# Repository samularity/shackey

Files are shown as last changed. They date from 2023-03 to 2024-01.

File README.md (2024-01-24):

# shackey 

### a simple ESP32-C3 SSH Client  

It's main (and only goal) is to open or close the [shackspace portal](https://github.com/shackspace/portal300) with a button press on a keychain device. 

### $\color{#D29922}\textsf{\Large\&#x26A0;\kern{0.2cm}\normalsize  !! Hardware-Issues !! \Large\&#x26A0; }$ 

- LED2 Green is on in DeepSleep FIX: Remove R7
- U4 XB6042J2SV-L is not working as expected
    - FIX: Bridge B_GND and GND
    - !Warning! This disables undervoltage protection

### How it works

- deepsleep
- Read two buttons (and Reset Pin) to open or close
- connect to wifi
- open a SSH session with your private key on a remote server
- provide a webserver to upload or delete your key

```mermaid
graph TD
    NodeStart((deepsleep)) --> wakeup -- wakup-source --> NodeWAKE{ } 

    wakeup -- enable --> NodeTimer{{45sec watchdog timer}} -. Timeout .-> NodeZZZ

    NodeWAKE -->|"BtnRst || Btn1+2"| NodeK(["setup-mode"]) -->  NodeClient
    NodeClient --> NodeClient
    NodeClient["wait for client"] --> connected -- disable --> NodeTimer

    NodeWAKE -->|Btn1| NodeJ([open]) -- set cmd=open--> NodeWIFI
    NodeWAKE -->|Btn2| NodeI([close]) -- set cmd=close--> NodeWIFI

    NodeWIFI["connect to wifi"] -- connected --> NodeCMD["ssh cmd"] -- got response --> NodeZZZ
    NodeWIFI-->NodeWIFI
    NodeCMD --> NodeCMD

    NodeWAKE -->|BtnRst| NodeZZZ  

    NodeZZZ((deepsleep))
```

### Software components used
- libssh2 ~~latest version~~ [463449fb](https://github.com/libssh2/libssh2/tree/463449fb9ee7dbe5fbe71a28494579a9a6890d6d) is used without any modifications.  
- It's arduino free without any outdated dependencies or additional overhead.  
- Its based on the latest espidf supported by platformio.

### ESP32-Connection

| PIN-Number | ESP-Pin Name | Description  |
|----|---|---|
|  6 | GPIO2 | 10k Pullup |
| 14 | GPIO8 | 10k Pullup |
| 15 | GPIO9 | BOOT |
|  4 | GPIO0 / XTAL_32K_P | Enable ADC |
| 27 | GPIO20 / U0RXD | ADC |
|  9 | GPIO4 / MTMS | SW1 Close (High when pressed) |
| 10 | GPIO5 / MTDI | SW2 Open (High pressed) |
| 16 | GPIO10 | LED1 Green |
| 12 | GPIO6 / MTCK | LED1 Red |
| 13 | GPIO7 / MTDO | LED1 Blue |
| 18 | GPIO11 / VDD_SPI | LED2 Green |
|  8 | GPIO3 | LED2 Red |
|  5 | GPIO1 / XTAL_32K_N | LED2 Blue |
| 28 | GPIO21 / U0TXD | TX-Testpin |
|  7 | Chip_EN | Reset |

### Device-Setup

- short the boot pin and upload firmware
- enter setup-mode by pressing both buttons on startup
- upload you private and public key with the following name
  "key.pub" und "key"

### thx & refs

- https://github.com/libssh2/libssh2
- https://github.com/espressif/esp-idf/tree/master/examples/
- https://www.ewan.cc/?q=node/157
- https://github.com/ewpa/LibSSH-ESP32
- https://github.com/nopnop2002/esp-idf-ssh-client
- https://wcalc.sourceforge.net/cgi-bin/coplanar.cgi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

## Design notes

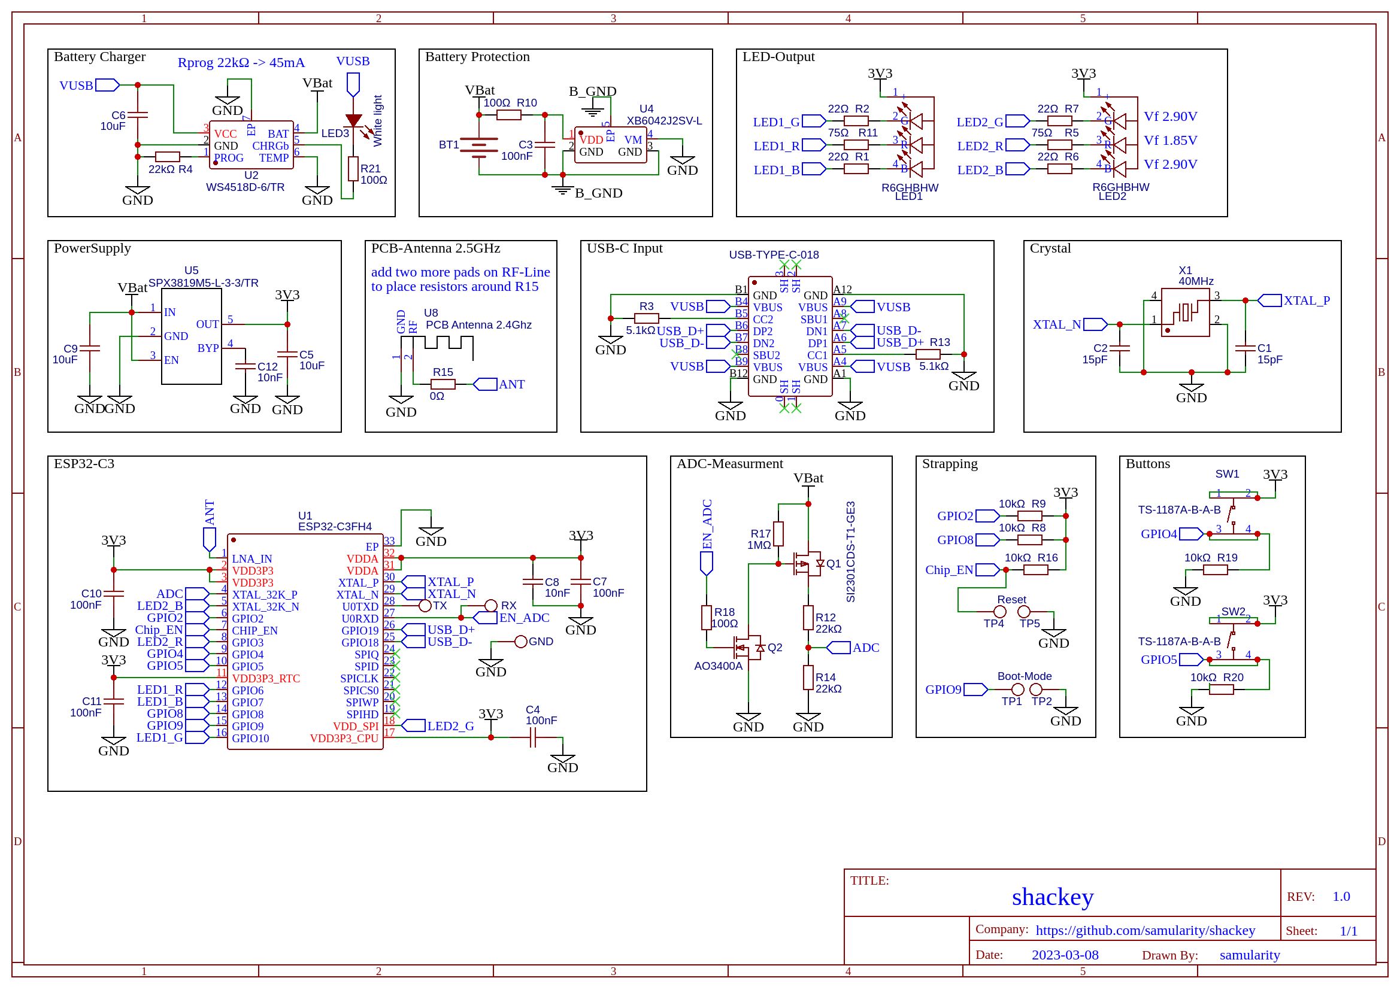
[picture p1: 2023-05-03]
hardware/schematic_shackey_final_1mmslot_2023-04-06.png

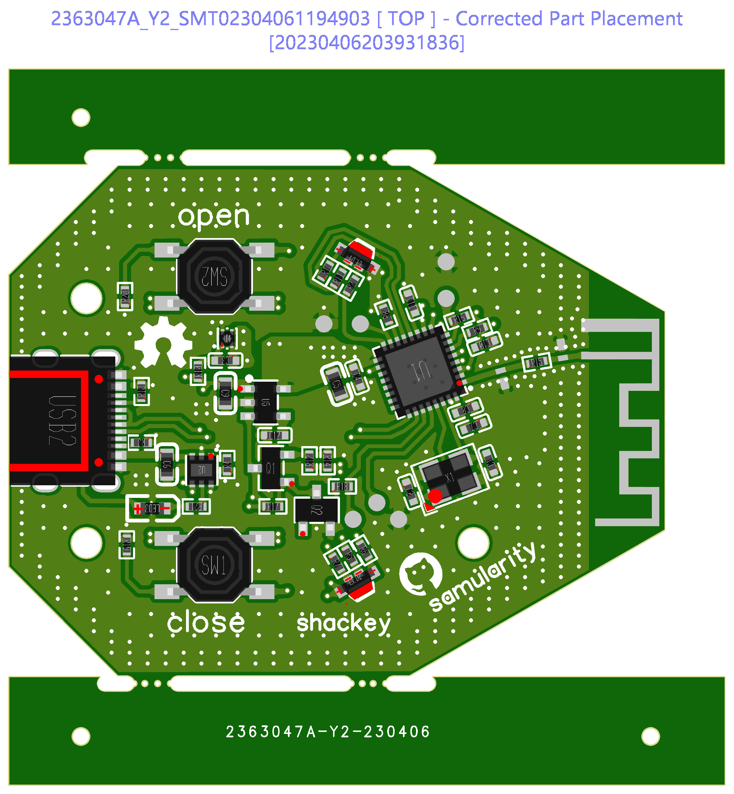
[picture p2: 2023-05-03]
hardware/pcb_shackey_final_1mmslot_2023-04-06.png

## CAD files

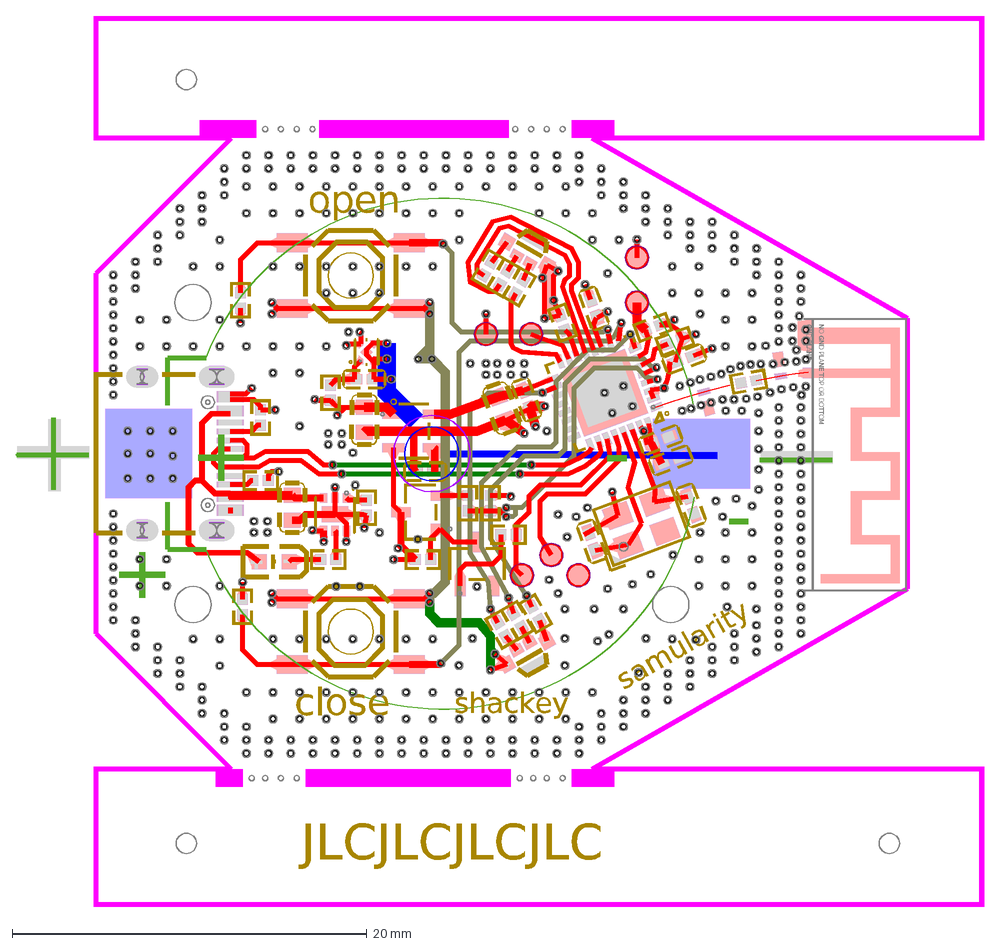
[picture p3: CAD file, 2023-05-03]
hardware/outline_shackey_final_1mmslot_2023-04-06.dxf
+
-
open
close
samularity
shackey
JLCJLCJLCJLC
GND PLANE
NO GND PLANE TOP OR BOTTOM

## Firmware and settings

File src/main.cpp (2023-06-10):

// Stack size needed to run SSH and the command parser.
const unsigned int configSTACK = 51200;

#include <errno.h>
#include <stdio.h>
#include <stdlib.h>
#include <string.h>
#include "driver/uart.h"
#include "esp_vfs_dev.h"
#include "driver/gpio.h"
#include "driver/ledc.h"
#include "nvs_flash.h"
#include "nvs.h"
#include "esp_timer.h"
#include "esp_log.h"
//own header
#include "pwrmgr.h"
#include "ssh.h"
#include "sspiffs.h"
#include "wifi.h"
#include "webserver.h"
#include "dns_server.h"

/*
| PIN-Number | ESP-Pin Name | Description  |
|----|----------------------|--------------|
|  4 | GPIO0 / XTAL_32K_P   | Enable ADC   |
| 27 | GPIO20 / U0RXD       | ADC          |
|  9 | GPIO4 / MTMS         | SW1 Close (High when pressed) |
| 10 | GPIO5 / MTDI         | SW2 Open (High pressed) |
| 16 | GPIO10               | LED1 Green   |
| 12 | GPIO6 / MTCK         | LED1 Red     |
| 13 | GPIO7 / MTDO         | LED1 Blue    |
| 18 | GPIO11 / VDD_SPI     | LED2 Green   |
|  8 | GPIO3                | LED2 Red     |
|  5 | GPIO1 / XTAL_32K_N   | LED2 Blue    |
*/
#define GPIO_ADC_ENABLE GPIO_NUM_0
#define GPIO_ADC_READ GPIO_NUM_20

#define GPIO_SW_CLOSE GPIO_NUM_4
#define GPIO_SW_OPEN GPIO_NUM_5

#define GPIO_LED1_RED GPIO_NUM_6
#define GPIO_LED1_GREEN GPIO_NUM_10
#define GPIO_LED1_BLUE GPIO_NUM_7

#define GPIO_LED2_RED GPIO_NUM_3
#define GPIO_LED2_GREEN GPIO_NUM_11 //DOES NOT WORK as GPIO, RESERVED for VDD_SPI
#define GPIO_LED2_BLUE GPIO_NUM_1

#define LEDC_TIMER              LEDC_TIMER_0
#define LEDC_MODE               LEDC_LOW_SPEED_MODE
#define LEDC_CHANNEL            LEDC_CHANNEL_0
#define LEDC_DUTY_RES           LEDC_TIMER_13_BIT // Set duty resolution to 13 bits
#define LEDC_DUTY               (1000) // Set duty to 50%. ((2 ** 13) - 1) * 50% = 4095  max 8191
#define LEDC_FREQUENCY          (5000) // Frequency in Hertz. Set frequency at 5 kHz



EventGroupHandle_t s_wifi_event_group;
EventGroupHandle_t xEventGroup;

int TASK_FINISH_BIT	= BIT4;

void TimeoutLoop(void *pvParameter){

  vTaskDelay(1000 / portTICK_PERIOD_MS);//wait 1 second to make sure buttons are released after setup-mode

 
  while (1){
    vTaskDelay(100 / portTICK_PERIOD_MS);

    if (1 == gpio_get_level(GPIO_SW_OPEN) &&  1 == gpio_get_level(GPIO_SW_CLOSE) ) {
      //abort whatever is going on
      printf("abort!\n");
      vTaskDelay(1000 / portTICK_PERIOD_MS);
      enterDeepsleep();
    }

    if ((esp_timer_get_time() > 45*1000*1000)){//uptime > 45 sec 
      //check if we are in setup mode and a client is connected
      if ( (xEventGroupGetBits(s_wifi_event_group) & WIFI_CLIENT_CONNECTED_BIT) ){
        printf("stay awake forever\n");
      }
      else{
        printf("took too long\n");
        enterDeepsleep();
      }
    } 
  }
  vTaskDelete( NULL ); //exit
}


void SetupMode (void *pvParameter){

  //esp_log_level_set("wifi", ESP_LOG_DEBUG);
  wifi_init_softap();
  start_webserver();
  start_dns_server();

  //idle forever, exit is handled in TimeoutLoop
  while (1){ vTaskDelay(1000 / portTICK_PERIOD_MS); }
}


extern "C" void app_main() {
  
  sshParameter cfg = {
    .username = "close",
    .hostname = "portal.shackspace.de",
    .port = 22,
    .password = {'\0'},
    .publickey = "/spiffs/key.pub",
    .privatekey = "/spiffs/key",
    .cmd = {'\0'},
  };

  // Use the expected blocking I/O behavior.
  setvbuf(stdin, NULL, _IONBF, 0);
  setvbuf(stdout, NULL, _IONBF, 0);

  //GPIO-INIT

  //configure inputs
	gpio_config_t io_conf;
	io_conf.intr_type = GPIO_INTR_DISABLE;
	io_conf.mode = GPIO_MODE_INPUT;
  io_conf.pin_bit_mask = ( (1ULL<<GPIO_SW_CLOSE) | (1ULL<<GPIO_SW_OPEN) );
	io_conf.pull_down_en = GPIO_PULLDOWN_ENABLE;
	io_conf.pull_up_en = GPIO_PULLUP_DISABLE;
	gpio_config(&io_conf);

	io_conf.pin_bit_mask = (1ULL<<GPIO_ADC_READ);
  io_conf.pull_up_en = GPIO_PULLUP_DISABLE;
	io_conf.pull_down_en = GPIO_PULLDOWN_DISABLE;
	gpio_config(&io_conf);

  //configure outputs
	io_conf.mode = GPIO_MODE_OUTPUT;
	io_conf.pin_bit_mask = ( (1ULL<<GPIO_ADC_ENABLE) |  (1ULL<<GPIO_LED1_RED) | (1ULL<<GPIO_LED1_GREEN) | (1ULL<<GPIO_LED1_BLUE) | (1ULL<<GPIO_LED2_RED) | (1ULL<<GPIO_LED2_BLUE)  );
  io_conf.pull_up_en = GPIO_PULLUP_DISABLE;
  io_conf.pull_down_en = GPIO_PULLDOWN_DISABLE;
  gpio_config(&io_conf);

//Disable all LEDs

  gpio_set_level(GPIO_LED2_BLUE, 0); //start led
  gpio_set_level(GPIO_LED1_RED, 1);
  gpio_set_level(GPIO_LED1_GREEN, 1);
  gpio_set_level(GPIO_LED1_BLUE, 1);
  gpio_set_level(GPIO_LED2_RED, 1);
	gpio_set_level(GPIO_LED2_GREEN, 1);


  uart_driver_install ((uart_port_t)CONFIG_ESP_CONSOLE_UART_NUM, 256, 0, 0, NULL, 0);
  esp_vfs_dev_uart_use_driver(CONFIG_ESP_CONSOLE_UART_NUM);

 // Prepare and then apply the LEDC PWM timer configuration
    ledc_timer_config_t ledc_timer = {
        .speed_mode       = LEDC_MODE,
        .duty_resolution  = LEDC_DUTY_RES,
        .timer_num        = LEDC_TIMER,
        .freq_hz          = LEDC_FREQUENCY,  // Set output frequency at 5 kHz
        .clk_cfg          = LEDC_AUTO_CLK
    };
    ESP_ERROR_CHECK(ledc_timer_config(&ledc_timer));

    // Prepare and then apply the LEDC PWM channel configuration
    ledc_channel_config_t ledc_channel = {
        .gpio_num       = GPIO_LED1_GREEN,
        .speed_mode     = LEDC_MODE,
        .channel        = LEDC_CHANNEL,
        .intr_type      = LEDC_INTR_DISABLE,
        .timer_sel      = LEDC_TIMER,
        .duty           = 0, // Set duty to 0%  //[0, (2**duty_resolution) - 1] 
        .hpoint         = 0,
        .flags          = 1
    };

  ledc_channel_config(&ledc_channel);

  printf("starting...\n");

  esp_log_level_set("SSH", ESP_LOG_DEBUG);

  printf("%s:%d: %llums\n",__FILE__ , __LINE__ , (uint64_t) (esp_timer_get_time()/1000) );

  s_wifi_event_group = xEventGroupCreate();
  xEventGroupClearBits( s_wifi_event_group, WIFI_CONNECTED_BIT || WIFI_FAIL_BIT || WIFI_CLIENT_CONNECTED_BIT );

  xTaskCreate(TimeoutLoop, "TimeoutLoop", 1024, NULL, (tskIDLE_PRIORITY + 1) , NULL);

  if (ESP_OK == initSPIFFS()){
    printf("sspifs init ok\n");
    printSPIFFSinfo();
  }
  else{
    printf("sspifs init failed\n");//no files, no key, just give up
    enterDeepsleep();
  }

  esp_err_t err = nvs_flash_init();
  if (err == ESP_ERR_NVS_NO_FREE_PAGES || err == ESP_ERR_NVS_NEW_VERSION_FOUND) {
      printf("nvs_flash_init failed");
  }

  switch (wakeSelector()){   
      case CMD_OPEN:  
          strcpy(cfg.username , "open-front");
          printf("ssh cmd open\n"); 
          ledc_set_duty(LEDC_MODE, LEDC_CHANNEL, 450);
          ledc_update_duty(LEDC_MODE, LEDC_CHANNEL);
          break;
      case CMD_CLOSE: 
          strcpy(cfg.username, "close");  
          printf("ssh cmd stop\n");   
          gpio_set_level(GPIO_LED1_RED, 0);
          break;
      default:     
        printf("UNKNOWN!/Setup-Mode\n");
        gpio_set_level(GPIO_LED1_BLUE, 0);
        xTaskCreate(SetupMode, "setup", 1024*8, NULL, (tskIDLE_PRIORITY + 1) , NULL); 
        while(1) {vTaskDelay(10000 / portTICK_PERIOD_MS);}  //idle forever, deep sleep is entered in TimeoutLoop task
      break;
  }

  esp_netif_init();
  wifi_init_sta();

  /* Wait for Wi-Fi connection */
  xEventGroupWaitBits(s_wifi_event_group, WIFI_CONNECTED_BIT, false, true, portMAX_DELAY);

  printf("starting ssh things\n");

  xEventGroup = xEventGroupCreate();// Create Eventgroup for ssh response
  xEventGroupClearBits( xEventGroup, TASK_FINISH_BIT );
      
  xTaskCreatePinnedToCore(&ssh_task, "ssh", 1024*8, (void *) &cfg , tskIDLE_PRIORITY , NULL, portNUM_PROCESSORS - 1);

  // Wait for ssh finish.
  xEventGroupWaitBits( xEventGroup,
    TASK_FINISH_BIT,	/* The bits within the event group to wait for. */
    pdTRUE,				/* HTTP_CLOSE_BIT should be cleared before returning. */
    pdFALSE,			/* Don't wait for both bits, either bit will do. */
    portMAX_DELAY);		/* Wait forever. */


  printf("ssh done, sleep\n");
  printf("uptime: %llums\n", (uint64_t) (esp_timer_get_time()/1000) );
  enterDeepsleep();

  while (1){
    vTaskDelay(1000 / portTICK_PERIOD_MS);
  }
}

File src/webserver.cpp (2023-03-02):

#include <stdio.h>
#include <string.h>
#include <sys/param.h>
#include <sys/unistd.h>
#include <sys/stat.h>
#include <dirent.h>

#include "esp_err.h"
#include "esp_log.h"

#include "esp_vfs.h"
#include "esp_spiffs.h"
#include "esp_http_server.h"

#include "webserver.h"

/* Max length a file path can have on storage */
#define FILE_PATH_MAX (ESP_VFS_PATH_MAX + CONFIG_SPIFFS_OBJ_NAME_LEN)

/* Max size of an individual file. Make sure this
 * value is same as that set in upload_script.html */
#define MAX_FILE_SIZE   (200*1024) // 200 KB
#define MAX_FILE_SIZE_STR "200KB"

/* Scratch buffer size */
#define SCRATCH_BUFSIZE  8192

struct file_server_data {
    /* Base path of file storage */
    char base_path[ESP_VFS_PATH_MAX + 1];

    /* Scratch buffer for temporary storage during file transfer */
    char scratch[SCRATCH_BUFSIZE];
};


static esp_err_t http_resp_dir_html(httpd_req_t *req, const char *dirpath);


static const char *TAG = "webserver";

extern const char root_start[] asm("_binary_root_html_start");
extern const char root_end[] asm("_binary_root_html_end");

// HTTP GET Handler
static esp_err_t root_get_handler(httpd_req_t *req)
{
    //const uint32_t root_len = root_end - root_start;

    //ESP_LOGI(TAG, "Serve root");
    //httpd_resp_set_type(req, "text/html");
    //httpd_resp_send(req, root_start, root_len);
    return http_resp_dir_html(req, "/spiffs/");
    //return ESP_OK;
}

static const httpd_uri_t root = {
    .uri = "/",
    .method = HTTP_GET,
    .handler = root_get_handler
};

// HTTP Error (404) Handler - Redirects all requests to the root page
esp_err_t http_404_error_handler(httpd_req_t *req, httpd_err_code_t err)
{
    // Set status
    httpd_resp_set_status(req, "302 Temporary Redirect");
    // Redirect to the "/" root directory
    httpd_resp_set_hdr(req, "Location", "/");
    // iOS requires content in the response to detect a captive portal, simply redirecting is not sufficient.
    httpd_resp_send(req, "Redirect to the captive portal", HTTPD_RESP_USE_STRLEN);

    ESP_LOGI(TAG, "Redirecting to root");
    return ESP_OK;
}


/* Send HTTP response with a run-time generated html consisting of
 * a list of all files and folders under the requested path.
 * In case of SPIFFS this returns empty list when path is any
 * string other than '/', since SPIFFS doesn't support directories */
static esp_err_t http_resp_dir_html(httpd_req_t *req, const char *dirpath)
{
    char entrypath[FILE_PATH_MAX];
    char entrysize[16];
    const char *entrytype;

    struct dirent *entry;
    struct stat entry_stat;

    DIR *dir = opendir(dirpath);
    const size_t dirpath_len = strlen(dirpath);

    /* Retrieve the base path of file storage to construct the full path */
    strlcpy(entrypath, dirpath, sizeof(entrypath));

    if (!dir) {
        ESP_LOGE(TAG, "Failed to stat dir : %s", dirpath);
        /* Respond with 404 Not Found */
        httpd_resp_send_err(req, HTTPD_404_NOT_FOUND, "Directory does not exist");
        return ESP_FAIL;
    }

    /* Send HTML file header */
    httpd_resp_sendstr_chunk(req, "<!DOCTYPE html><html><body>");

    /* Get handle to embedded file upload script */
    //extern const unsigned char upload_script_start[] asm("_binary_upload_script_html_start");
    //extern const unsigned char upload_script_end[]   asm("_binary_upload_script_html_end");
    extern const char upload_script_start[] asm("_binary_root_html_start");
    extern const char upload_script_end[] asm("_binary_root_html_end");
    const size_t upload_script_size = (upload_script_end - upload_script_start);

    /* Add file upload form and script which on execution sends a POST request to /upload */
    httpd_resp_send_chunk(req, (const char *)upload_script_start, upload_script_size);

    /* Send file-list table definition and column labels */
    httpd_resp_sendstr_chunk(req,
        "<table class=\"fixed\" width=\"100%\" border=\"1\">"
        "<col width=\"auto\" /><col width=\"auto\" /><col width=\"auto\" /><col width=\"auto\" />"
        "<thead><tr><th>Name</th><th>Type</th><th>Size (Bytes)</th><th>Delete</th></tr></thead>"
        "<tbody>");

    /* Iterate over all files / folders and fetch their names and sizes */
    while ((entry = readdir(dir)) != NULL) {
        entrytype = (entry->d_type == DT_DIR ? "directory" : "file");

        strlcpy(entrypath + dirpath_len, entry->d_name, sizeof(entrypath) - dirpath_len);
        if (stat(entrypath, &entry_stat) == -1) {
            ESP_LOGE(TAG, "Failed to stat %s : %s", entrytype, entry->d_name);
            continue;
        }
        sprintf(entrysize, "%ld", entry_stat.st_size);
        ESP_LOGI(TAG, "Found %s : %s (%s bytes)", entrytype, entry->d_name, entrysize);

        /* Send chunk of HTML file containing table entries with file name and size */
        //httpd_resp_sendstr_chunk(req, "<tr><td><a href=\"");
        httpd_resp_sendstr_chunk(req, "<tr><td>");
        //httpd_resp_sendstr_chunk(req, req->uri);
        //httpd_resp_sendstr_chunk(req, entry->d_name);
        //if (entry->d_type == DT_DIR) {
        //    httpd_resp_sendstr_chunk(req, "/");
        //}
        //httpd_resp_sendstr_chunk(req, "\">");
        httpd_resp_sendstr_chunk(req, entry->d_name);
        httpd_resp_sendstr_chunk(req, "</td><td>");
        //httpd_resp_sendstr_chunk(req, "</a></td><td>");
        httpd_resp_sendstr_chunk(req, entrytype);
        httpd_resp_sendstr_chunk(req, "</td><td>");
        httpd_resp_sendstr_chunk(req, entrysize);
        httpd_resp_sendstr_chunk(req, "</td><td>");
        httpd_resp_sendstr_chunk(req, "<form method=\"post\" action=\"/delete");
        httpd_resp_sendstr_chunk(req, req->uri);
        httpd_resp_sendstr_chunk(req, entry->d_name);
        httpd_resp_sendstr_chunk(req, "\"><button class=\"button\" type=\"submit\">Delete</button></form>");
        httpd_resp_sendstr_chunk(req, "</td></tr>\n");
    }
    closedir(dir);

    /* Finish the file list table */
    httpd_resp_sendstr_chunk(req, "</tbody></table>");

    /* Send remaining chunk of HTML file to complete it */
    httpd_resp_sendstr_chunk(req, "</div></body></html>");

    /* Send empty chunk to signal HTTP response completion */
    httpd_resp_sendstr_chunk(req, NULL);
    return ESP_OK;
}
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

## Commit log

2023-02-10 add libs for direct usb upload
    esp32-c3 has a built in debugger which requires more libs to be used
2023-02-12 replace arduino spiffs with native
    [main.cpp, spiffs.cpp]
2023-02-16 first arduino free version
    [partitions.csv]
2023-03-02 update fileserver
    better look with css
    remove download option. Keys should stay on the device - write or delete only
2023-03-02 update readme: add flowchart
2023-03-03 readme: update flowchart
2023-03-12 update reset behaviour
    match the doku now, on plain reset enter deep sleep, if button2 is additionally pressed, enter setup mode
    [main.cpp]
2023-05-03 add schematic and layout
    [outline_shackey_final_1mmslot_2023-04-06.dxf]
2023-06-10 rework setup-mode and led's
    [main.cpp]
2024-04-30 Update pwrmgr.cpp
    fix type
    [pwrmgr.cpp]
2026-11-06 update readme
    swap buttons in flowchart, fix warning icon and typos
2026-11-06 fix printf var type
2026-11-07 readme: flowchart folded
